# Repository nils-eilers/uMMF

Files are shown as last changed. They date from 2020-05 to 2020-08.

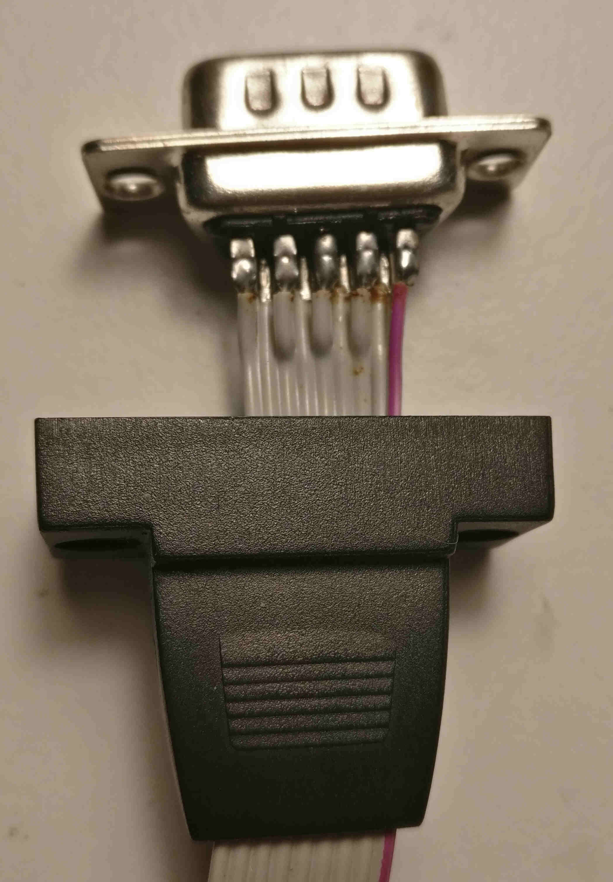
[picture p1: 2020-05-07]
doc/subd9-dtk-intel.jpg

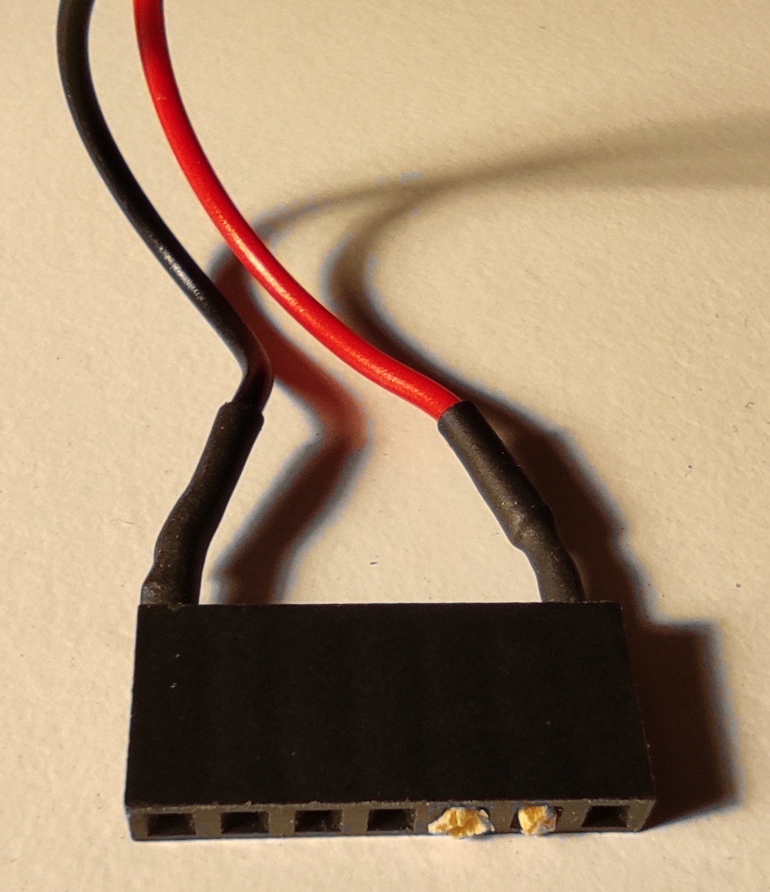
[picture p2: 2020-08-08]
doc/cable-j5-8032-j11.jpg

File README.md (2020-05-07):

µMMF
====

The SuperPET is basically a Commodore CBM 8032 with two, later only one
extra boards in it which contain a 6809 CPU, 64 KB RAM and some ROMs. This
project aims to provide a replacement for these extra board(s) with
slightly more modern parts, enabling every CBM 8032 owner to upgrade his
machine to a SuperPET.

__This board requires a NMOS 6502. Do NOT use a CMOS 6502!__

The board will accept NMOS Motorola 6809E as well as CMOS Hitachi HD63C09E,
just ensure you get the E-type, not those without appended ‘E’ because
their pinout is different. The version without E has the clock generator
integrated, the E-version requires an external clock generator.

LED D1 is a low current (2 mA) type. It is used solely for debug purposes,
the original SuperPET does not contain such a LED, so you may omit it.

IC3 74HCT11 has to be a HCT type. Do not use HC, LS or anything else
because HCT was chosen to match the voltage level requirements.

Please note that some modifications on the original CBM 8032 motherboard
must been made, as on the original SuperPET boards:

- 16 MHz clock signal provided at pin 35 of the 6502 CPU socket (patched in
  with a wire)
- 2532 character EPROM replacement

Refer to the pictures provided in the doc subdirectory for information
about how to provide the 16 MHz clock signal at pin 35. These differ
slightly from board version to board version.

An Atmel AT29C010 Flash ROM is required, programmed with roms/superpet.bin
and write protected.

The CPLD code was written in Verilog. These were my first steps with
Verilog, so please bear with me. Use Altera Quartus II 13.0.1 SP1 to
compile the Verilog and program the CPLD, newer versions don't support
the MAX7000 CPLD series any longer. The binary to program the CPLD is
located at cpld/output_files/superpet.pof.

An interactive bill of materials is available at `bom/ibom.html`

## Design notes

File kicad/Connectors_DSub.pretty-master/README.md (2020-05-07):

### Connectors_DSub

Footprints for DB / Dsubmiature / MicroD footprints

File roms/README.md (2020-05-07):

µMMF ROMs
=========

Nothing spectacular here, the waterloo ROM files are just concatenated
and empty spaces filled with $FF with the help of the Arnold Assembler AS,
freely available from http://john.ccac.rwth-aachen.de:8000/as/index.html

The generated file `superpet.bin` is to be flashed into an Atmel AT29C010A.
Ensure to enable the write protection of the flash ROM afterwards or the
contents will corrupt sooner or later.

Burn the file `characters.901640-01.bin` into a 2532 EPROM and replace
the character generator with it, otherwise you won't be able to see
anything.

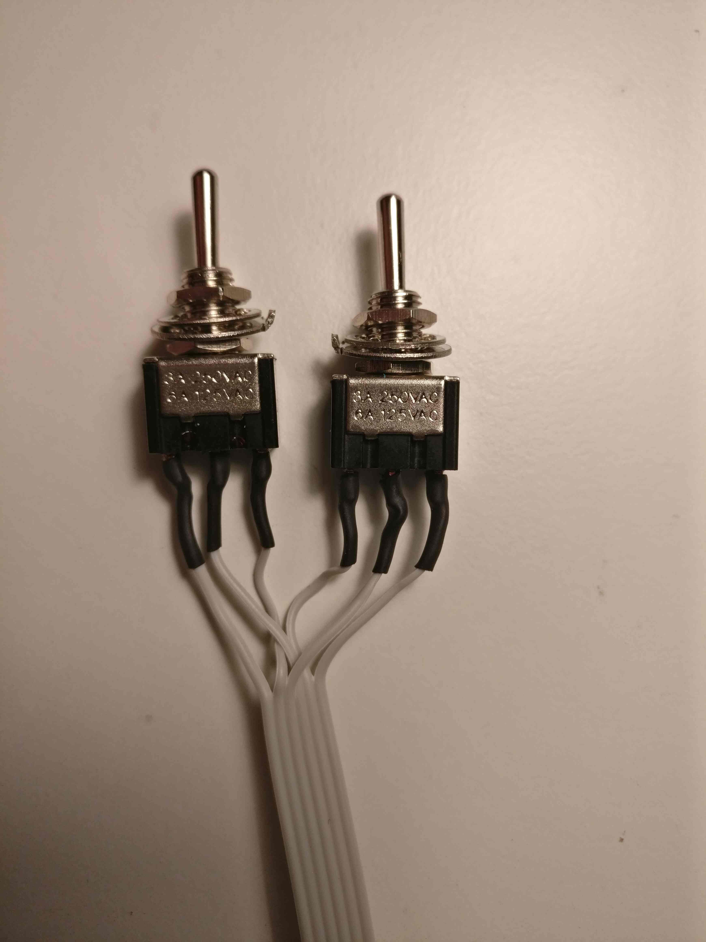
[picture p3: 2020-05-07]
doc/superpet-switches.jpg

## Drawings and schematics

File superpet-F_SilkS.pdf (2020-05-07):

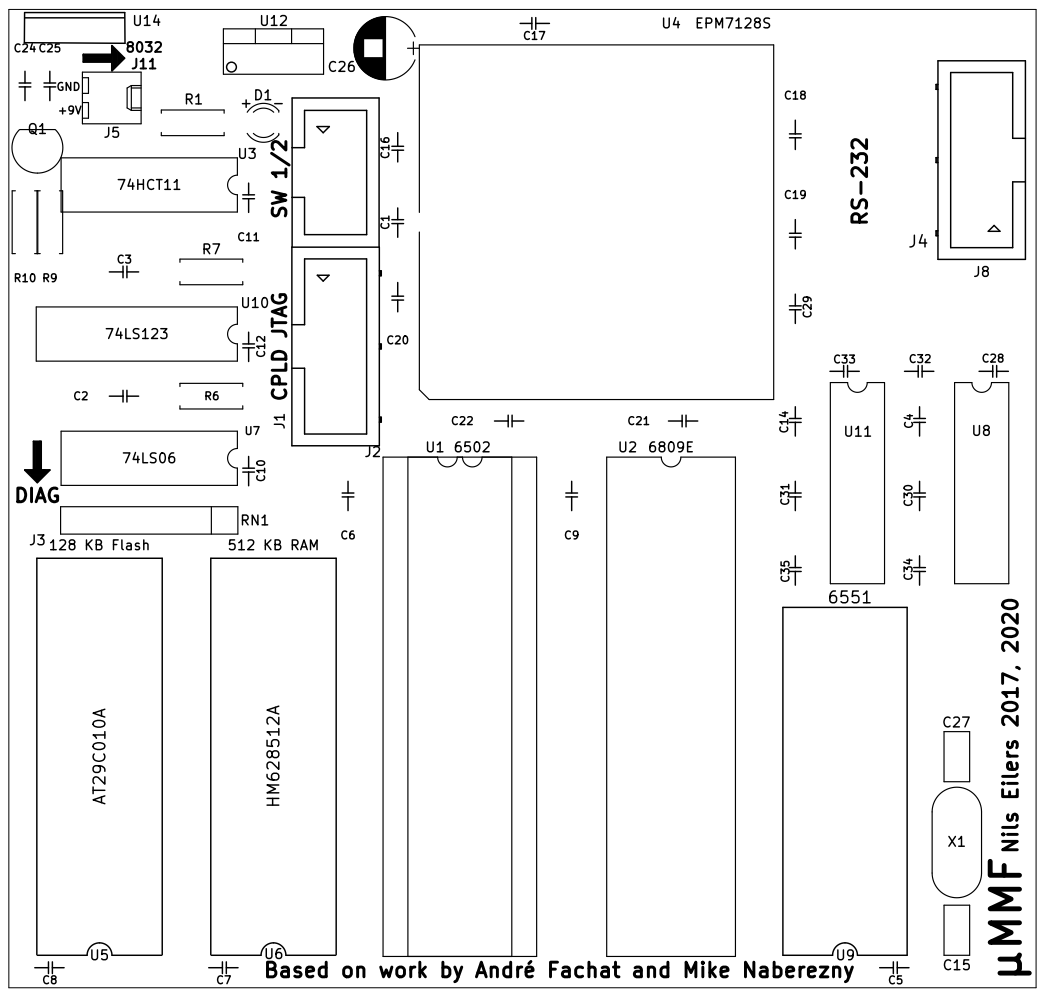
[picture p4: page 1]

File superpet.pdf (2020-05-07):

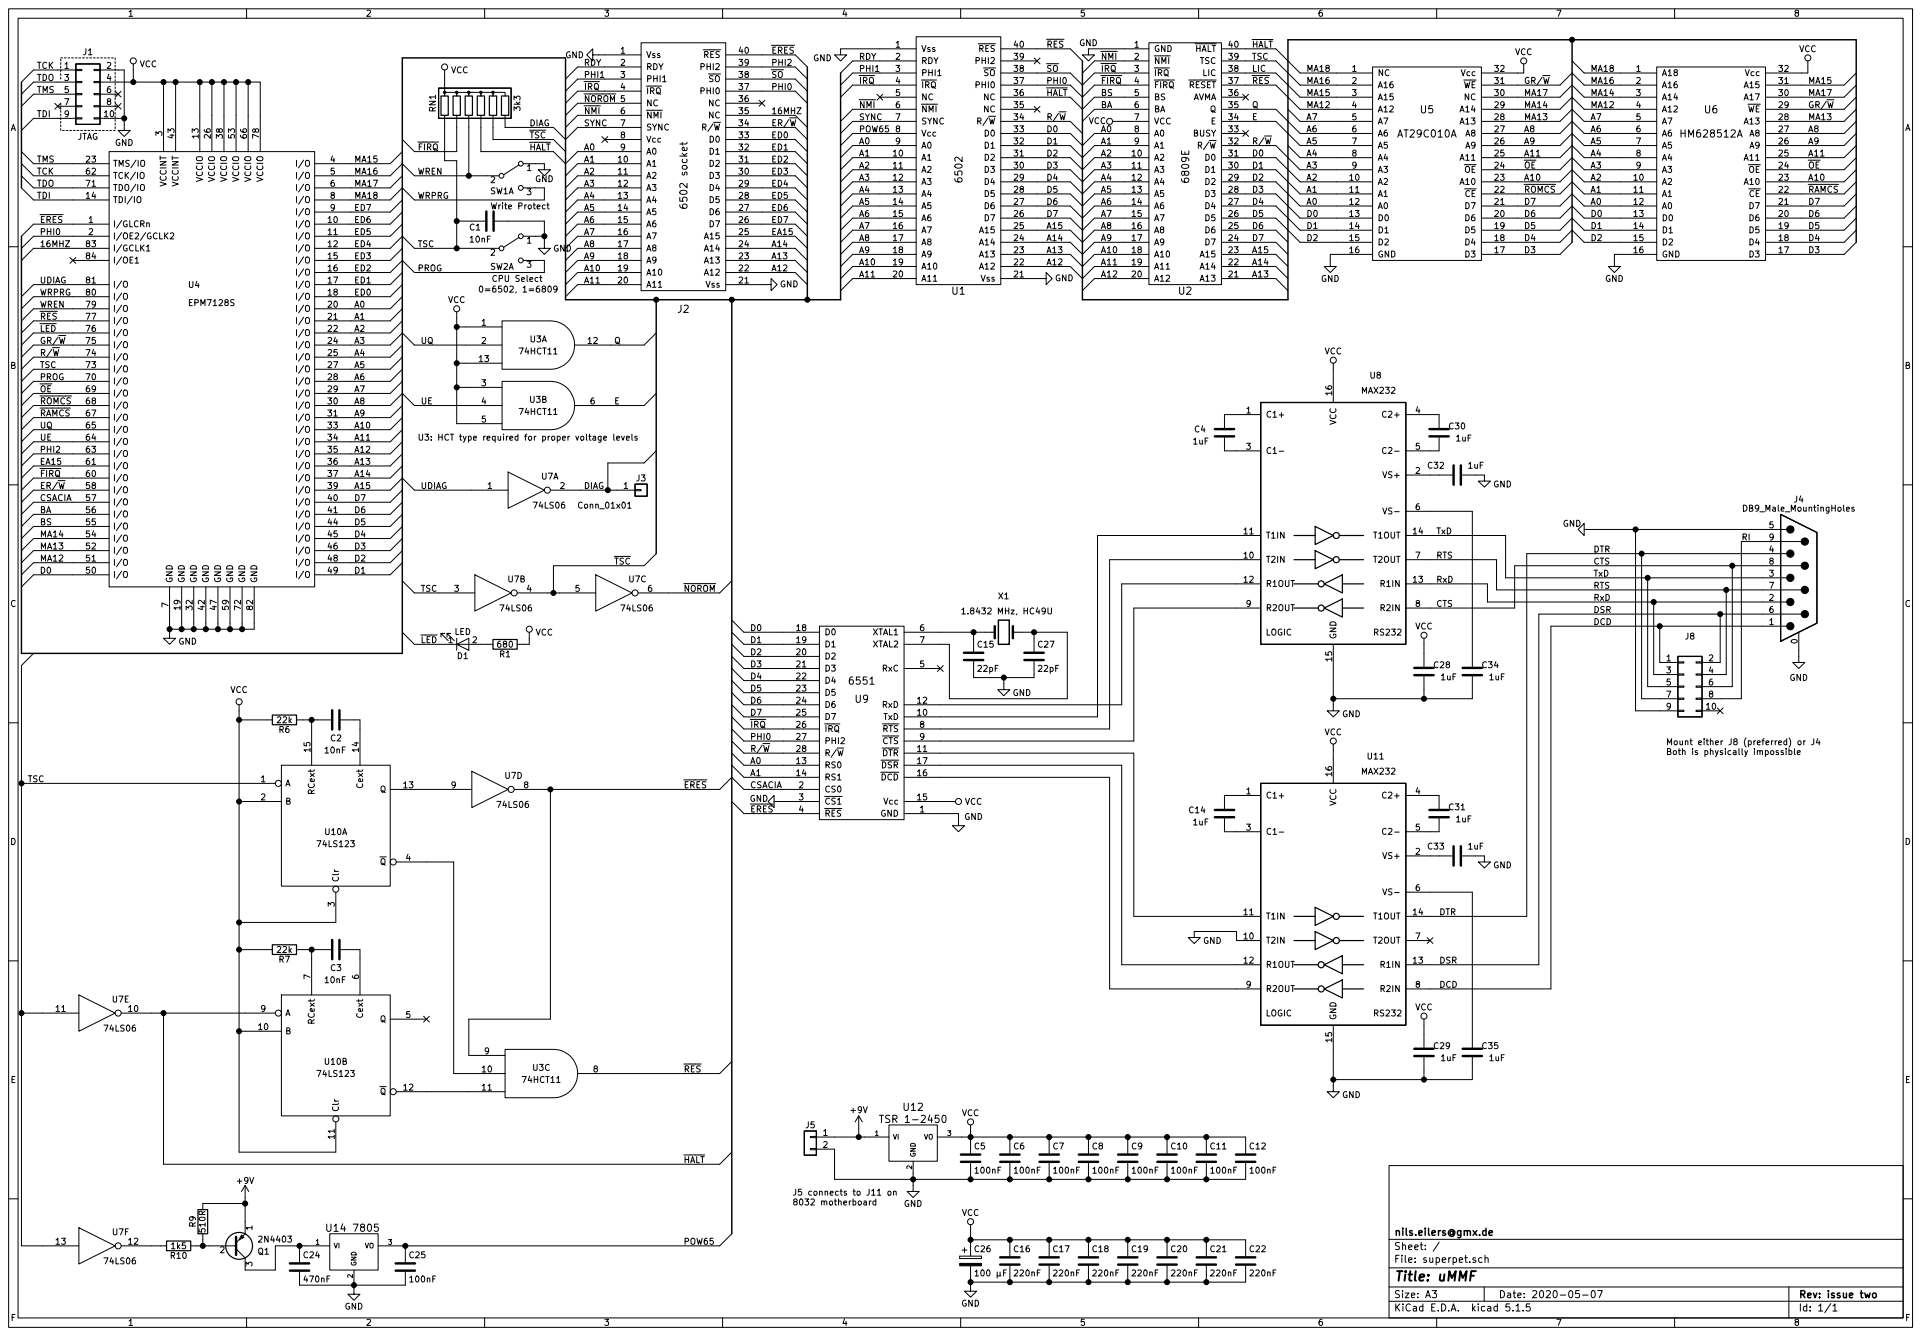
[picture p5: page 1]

A0 ROMCS R/W
WREN WRPRG
TDO

RTS RxD

TxD

Both is physically impossible

File: superpet.sch Sheet: / nils.eilers@gmx.de

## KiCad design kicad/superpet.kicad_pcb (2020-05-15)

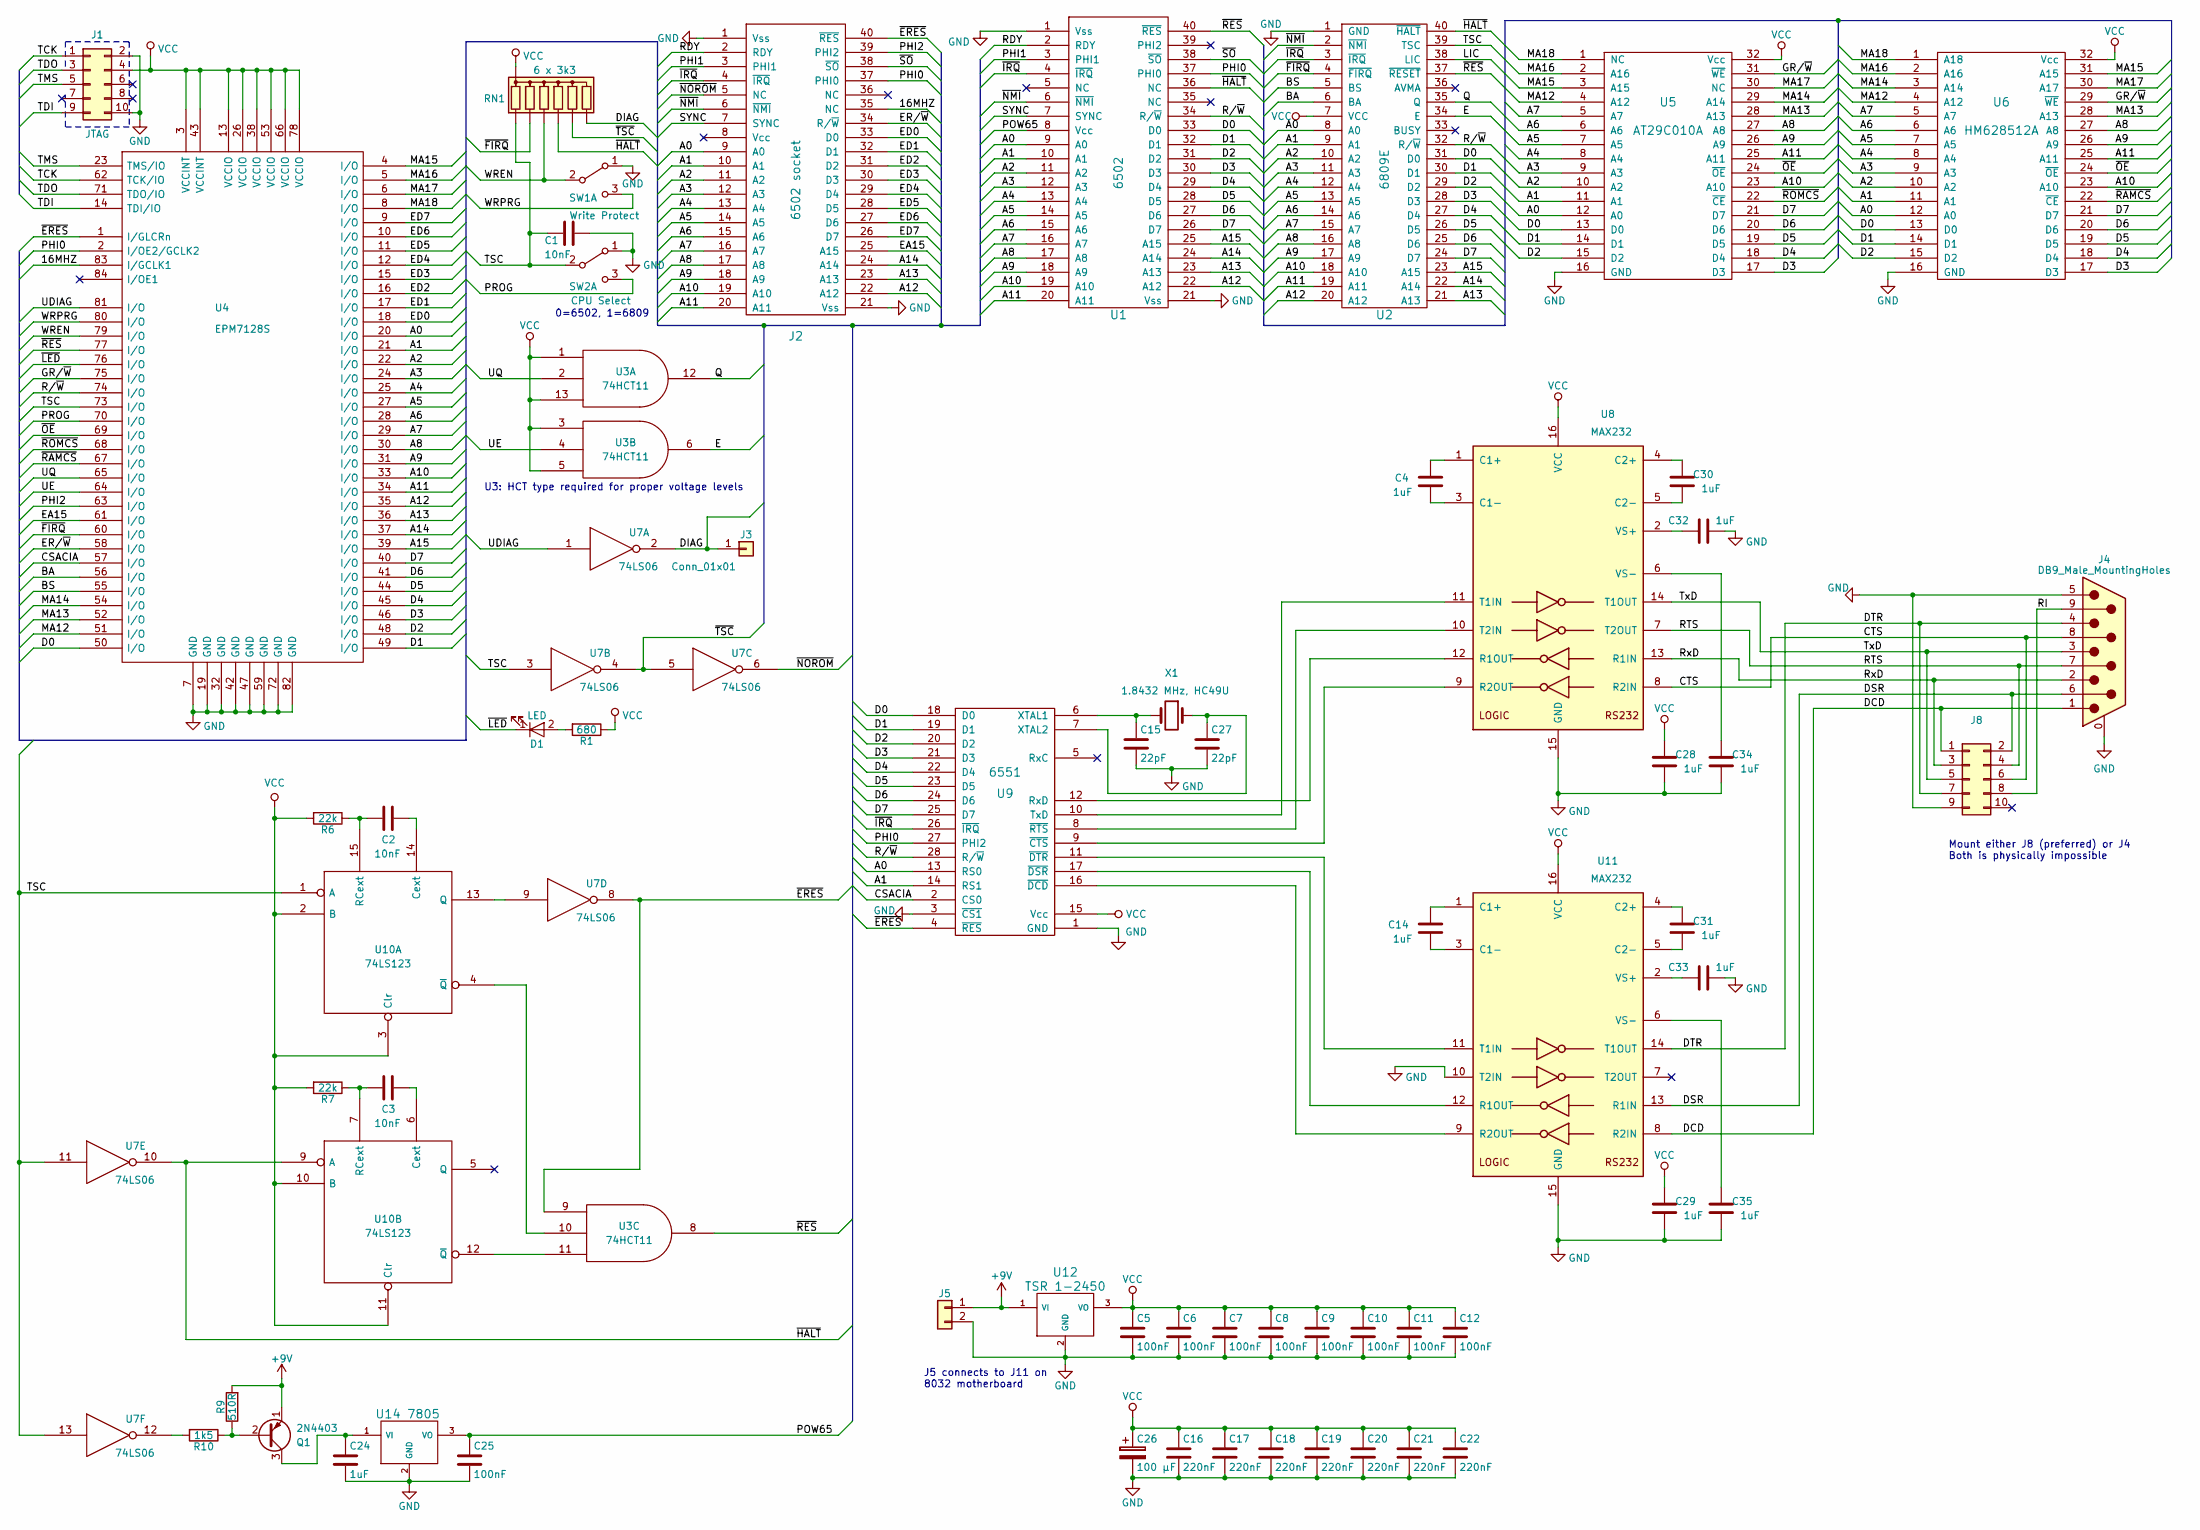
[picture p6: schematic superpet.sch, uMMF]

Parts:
C1, C2, C3: 10nF; C_Disc_D5.0mm_W2.5mm_P5.00mm
C4, C14, C24, C28, C29, C30, C31, C32, C33, C34, C35: 1uF; C_Disc_D5.0mm_W2.5mm_P5.00mm
C5, C6, C7, C8, C9, C10, C11, C12, C25: 100nF; C_Disc_D5.0mm_W2.5mm_P5.00mm
C15, C27: 22pF; C_Disc_D5.0mm_W2.5mm_P2.50mm
C16, C17, C18, C19, C20, C21, C22: 220nF; C_Disc_D5.0mm_W2.5mm_P5.00mm
C26: 100 µF; CP_Radial_D6.3mm_P2.50mm
D1: LED; LED_D3.0mm
J1: JTAG; Multicomp_MC9A12-1034_2x05x2.54mm_Straight
J2: 6502 socket; DIP-40_W15.24mm
J3: Conn_01x01; SolderWirePad_single_1mmDrill
J4: DB9_Male_MountingHoles; DB9MC
J5: Conn_01x02; Molex_KK-6410-02_02x2.54mm_Straight
J8: Conn_02x05_Odd_Even; Multicomp_MC9A12-1034_2x05x2.54mm_Straight
Q1: 2N4403; TO-92
R1: 680; R_Axial_DIN0207_L6.3mm_D2.5mm_P7.62mm_Horizontal
R6, R7: 22k; R_Axial_DIN0207_L6.3mm_D2.5mm_P7.62mm_Horizontal
R9: 510R; R_Axial_DIN0207_L6.3mm_D2.5mm_P7.62mm_Horizontal
R10: 1k5; R_Axial_DIN0207_L6.3mm_D2.5mm_P7.62mm_Horizontal
RN1: 6 x 3k3; R_Array_SIP7
SW1: Write Protect; WSL_6W_HALF
SW2: CPU Select; WSL_6W_HALF
U1: 6502; DIP-40_W15.24mm
U2: 6809E; DIP-40_W15.24mm
U3: 74HCT11; DIP-14_W7.62mm
U4: EPM7128S; PLCC-84_THT-Socket
U5: AT29C010A; DIP-32-15.24
U6: HM628512A; DIP-32-15.24
U7: 74LS06; DIP-14_W7.62mm
U8, U11: MAX232; DIP-16_W7.62mm
U9: 6551; DIP-28
U10: 74LS123; DIP-16_W7.62mm
U12: TSR 1-2450; TO-220-3_Vertical
U14: 7805; TO-220-3_Vertical
X1: 1.8432 MHz, HC49U; Crystal_HC49-U_Vertical

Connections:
+9V: J5.1, Q1.1 (E), R9.2, U12.1 (VI)
/16MHZ: J2.35 (NC), U4.83 (I/GCLK1)
/A0: J2.9 (A0), U1.9 (A0), U2.8 (A0), U4.20 (I/O), U5.12 (A0), U6.12 (A0), U9.13 (RS0)
/A1: J2.10 (A1), U1.10 (A1), U2.9 (A1), U4.21 (I/O), U5.11 (A1), U6.11 (A1), U9.14 (RS1)
/A2: J2.11 (A2), U1.11 (A2), U2.10 (A2), U4.22 (I/O), U5.10 (A2), U6.10 (A2)
/A3: J2.12 (A3), U1.12 (A3), U2.11 (A3), U4.24 (I/O), U5.9 (A3), U6.9 (A3)
/A4: J2.13 (A4), U1.13 (A4), U2.12 (A4), U4.25 (I/O), U5.8 (A4), U6.8 (A4)
/A5: J2.14 (A5), U1.14 (A5), U2.13 (A5), U4.27 (I/O), U5.7 (A5), U6.7 (A5)
/A6: J2.15 (A6), U1.15 (A6), U2.14 (A6), U4.28 (I/O), U5.6 (A6), U6.6 (A6)
/A7: J2.16 (A7), U1.16 (A7), U2.15 (A7), U4.29 (I/O), U5.5 (A7), U6.5 (A7)
/A8: J2.17 (A8), U1.17 (A8), U2.16 (A8), U4.30 (I/O), U5.27 (A8), U6.27 (A8)
/A9: J2.18 (A9), U1.18 (A9), U2.17 (A9), U4.31 (I/O), U5.26 (A9), U6.26 (A9)
/A10: J2.19 (A10), U1.19 (A10), U2.18 (A10), U4.33 (I/O), U5.23 (A10), U6.23 (A10)
/A11: J2.20 (A11), U1.20 (A11), U2.19 (A11), U4.34 (I/O), U5.25 (A11), U6.25 (A11)
/A12: J2.22 (A12), U1.22 (A12), U2.20 (A12), U4.35 (I/O)
/A13: J2.23 (A13), U1.23 (A13), U2.21 (A13), U4.36 (I/O)
/A14: J2.24 (A14), U1.24 (A14), U2.22 (A14), U4.37 (I/O)
/A15: U1.25 (A15), U2.23 (A15), U4.39 (I/O)
/BA: U2.6 (BA), U4.56 (I/O)
/BS: U2.5 (BS), U4.55 (I/O)
/CSACIA: U4.57 (I/O), U9.2 (CS0)
/CTS: J4.8, J8.6, U8.8 (R2IN)
/D0: U1.33 (D0), U2.31 (D0), U4.50 (I/O), U5.13 (D0), U6.13 (D0), U9.18 (D0)
/D1: U1.32 (D1), U2.30 (D1), U4.49 (I/O), U5.14 (D1), U6.14 (D1), U9.19 (D1)
/D2: U1.31 (D2), U2.29 (D2), U4.48 (I/O), U5.15 (D2), U6.15 (D2), U9.20 (D2)
/D3: U1.30 (D3), U2.28 (D3), U4.46 (I/O), U5.17 (D3), U6.17 (D3), U9.21 (D3)
/D4: U1.29 (D4), U2.27 (D4), U4.45 (I/O), U5.18 (D4), U6.18 (D4), U9.22 (D4)
/D5: U1.28 (D5), U2.26 (D5), U4.44 (I/O), U5.19 (D5), U6.19 (D5), U9.23 (D5)
/D6: U1.27 (D6), U2.25 (D6), U4.41 (I/O), U5.20 (D6), U6.20 (D6), U9.24 (D6)
/D7: U1.26 (D7), U2.24 (D7), U4.40 (I/O), U5.21 (D7), U6.21 (D7), U9.25 (D7)
/DCD: J4.1, J8.1, U11.8 (R2IN)
/DIAG: J3.1, RN1.7 (R6), U7.2
/DSR: J4.6, J8.2, U11.13 (R1IN)
/DTR: J4.4, J8.7, U11.14 (T1OUT)
/E: U2.34 (E), U3.6
/EA15: J2.25 (A15), U4.61 (I/O)
/ED0: J2.33 (D0), U4.18 (I/O)
/ED1: J2.32 (D1), U4.17 (I/O)
/ED2: J2.31 (D2), U4.16 (I/O)
/ED3: J2.30 (D3), U4.15 (I/O)
/ED4: J2.29 (D4), U4.12 (I/O)
/ED5: J2.28 (D5), U4.11 (I/O)
/ED6: J2.27 (D6), U4.10 (I/O)
/ED7: J2.26 (D7), U4.9 (I/O)
/ER/~W: J2.34 (R/~W), U4.58 (I/O)
/GR/~W: U4.75 (I/O), U5.31 (~WE), U6.29 (~WE)
/LIC: U2.38 (LIC)
/MA12: U4.51 (I/O), U5.4 (A12), U6.4 (A12)
/MA13: U4.52 (I/O), U5.28 (A13), U6.28 (A13)
/MA14: U4.54 (I/O), U5.29 (A14), U6.3 (A14)
/MA15: U4.4 (I/O), U5.3 (A15), U6.31 (A15)
/MA16: U4.5 (I/O), U5.2 (A16), U6.2 (A16)
/MA17: U4.6 (I/O), U5.30 (NC), U6.30 (A17)
/MA18: U4.8 (I/O), U5.1 (NC), U6.1 (A18)
/PHI0: J2.37 (PHI0), U1.37 (PHI0), U4.2 (I/OE2/GCLK2), U9.27 (PHI2)
/PHI1: J2.3 (PHI1), U1.3 (PHI1)
/PHI2: J2.39 (PHI2), U4.63 (I/O)
/POW65: C25.1, U1.8 (Vcc), U14.3 (VO)
/PROG: SW2.3 (C), U4.70 (I/O)
/Q: U2.35 (Q), U3.12
/R/~W: U1.34 (R/~W), U2.32 (R/~W), U4.74 (I/O), U9.28 (R/~W)
/RDY: J2.2 (RDY), U1.2 (RDY)
/RI: J4.9, J8.8
/RTS: J4.7, J8.4, U8.7 (T2OUT)
/RxD: J4.2, J8.3, U8.13 (R1IN)
/SYNC: J2.7 (SYNC), U1.7 (SYNC)
/TCK: J1.1, U4.62 (TCK/IO)
/TDI: J1.9, U4.14 (TDI/IO)
/TDO: J1.3, U4.71 (TDO/IO)
/TMS: J1.5, U4.23 (TMS/IO)
/TSC: C1.2, RN1.2 (R1), SW2.2 (B), U2.39 (TSC), U4.73 (I/O), U7.3, U7.11, U7.13, U10.1 (A)
/TxD: J4.3, J8.5, U8.14 (T1OUT)
/UDIAG: U4.81 (I/O), U7.1
/UE: U3.4, U4.64 (I/O)
/UQ: U3.2, U4.65 (I/O)
/WREN: RN1.4 (R3), SW1.2 (B), U4.79 (I/O)
/WRPRG: SW1.3 (C), U4.80 (I/O)
/~ERES: J2.40 (~RES), U3.9, U4.1 (I/GLCRn), U7.8, U9.4 (~RES)
/~FIRQ: RN1.3 (R2), U2.4 (~FIRQ), U4.60 (I/O)
/~HALT: RN1.5 (R4), U1.36 (NC), U2.40 (~HALT), U7.10, U10.9 (A)
/~IRQ: J2.4 (~IRQ), U1.4 (~IRQ), U2.3 (~IRQ), U9.26 (~IRQ)
/~LED: D1.1 (K), U4.76 (I/O)
/~NMI: J2.6 (~NMI), U1.6 (~NMI), U2.2 (~NMI)
/~NOROM: J2.5 (NC), U7.6
/~OE: U4.69 (I/O), U5.24 (~OE), U6.24 (~OE)
/~RAMCS: U4.67 (I/O), U6.22 (~CE)
/~RES: U1.40 (~RES), U2.37 (~RESET), U3.8, U4.77 (I/O)
/~ROMCS: U4.68 (I/O), U5.22 (~CE)
/~SO: J2.38 (~SO), U1.38 (~SO)
/~TSC: RN1.6 (R5), U7.4, U7.5
GND: C1.1, C5.2, C6.2, C7.2, C8.2, C9.2, C10.2, C11.2, C12.2, C15.2, C16.2, C17.2, C18.2, C19.2, C20.2, C21.2, C22.2, C24.2, C25.2, C26.2, C27.2, C28.1, C29.1, C32.2, C33.2, C34.1, C35.1, J1.2, J1.10, J2.1 (Vss), J2.21 (Vss), J4.0 (PAD), J4.5, J5.2, J8.9, SW1.1 (A), SW2.1 (A), U1.1 (Vss), U1.21 (Vss), U2.1 (GND), U3.7 (GND), U4.7 (GND), U4.19 (GND), U4.32 (GND), U4.42 (GND), U4.47 (GND), U4.59 (GND), U4.72 (GND), U4.82 (GND), U5.16 (GND), U6.16 (GND), U7.7 (GND), U8.15 (GND), U9.1 (GND), U9.3 (~CS1), U10.8 (GND), U11.10 (T2IN), U11.15 (GND), U12.2 (GND), U14.2 (GND)
unnamed: C2.1, U10.14 (Cext)
unnamed: C2.2, R6.1, U10.15 (RCext)
unnamed: C3.1, U10.6 (Cext)
unnamed: C3.2, R7.1, U10.7 (RCext)
unnamed: C4.1, U8.3 (C1-)
unnamed: C4.2, U8.1 (C1+)
unnamed: C14.1, U11.3 (C1-)
unnamed: C14.2, U11.1 (C1+)
unnamed: C15.1, U9.6 (XTAL1), X1.2
unnamed: C24.1, Q1.3 (C), U14.1 (VI)
unnamed: C27.1, U9.7 (XTAL2), X1.1
unnamed: C30.1, U8.5 (C2-)
unnamed: C30.2, U8.4 (C2+)
unnamed: C31.1, U11.5 (C2-)
unnamed: C31.2, U11.4 (C2+)
unnamed: C32.1, U8.2 (VS+)
unnamed: C33.1, U11.2 (VS+)
unnamed: C34.2, U8.6 (VS-)
unnamed: C35.2, U11.6 (VS-)
unnamed: D1.2 (A), R1.2
unnamed: Q1.2 (B), R9.1, R10.1
unnamed: R10.2, U7.12
unnamed: U8.9 (R2OUT), U9.9 (~CTS)
unnamed: U8.10 (T2IN), U9.8 (~RTS)
unnamed: U8.11 (T1IN), U9.10 (TxD)
unnamed: U8.12 (R1OUT), U9.12 (RxD)
unnamed: U3.10, U10.4 (~Q)
unnamed: U3.11, U10.12 (~Q)
unnamed: U7.9, U10.13 (Q)
unnamed: U9.16 (~DCD), U11.9 (R2OUT)
unnamed: U9.11 (~DTR), U11.11 (T1IN)
unnamed: U9.17 (~DSR), U11.12 (R1OUT)
VCC: C5.1, C6.1, C7.1, C8.1, C9.1, C10.1, C11.1, C12.1, C16.1, C17.1, C18.1, C19.1, C20.1, C21.1, C22.1, C26.1, C28.2, C29.2, J1.4, R1.1, R6.2, R7.2, RN1.1 (common), U2.7 (VCC), U3.1, U3.3, U3.5, U3.13, U3.14 (VCC), U4.3 (VCCINT), U4.13 (VCCIO), U4.26 (VCCIO), U4.38 (VCCIO), U4.43 (VCCINT), U4.53 (VCCIO), U4.66 (VCCIO), U4.78 (VCCIO), U5.32 (Vcc), U6.32 (Vcc), U7.14 (VCC), U8.16 (VCC), U9.15 (Vcc), U10.2 (B), U10.3 (Clr), U10.10 (B), U10.11 (Clr), U10.16 (VCC), U11.16 (VCC), U12.3 (VO)

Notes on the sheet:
0=6502, 1=6809
U3: HCT type required for proper voltage levels
J5 connects to J11 on 8032 motherboard
Mount either J8 (preferred) or J4 Both is physically impossible

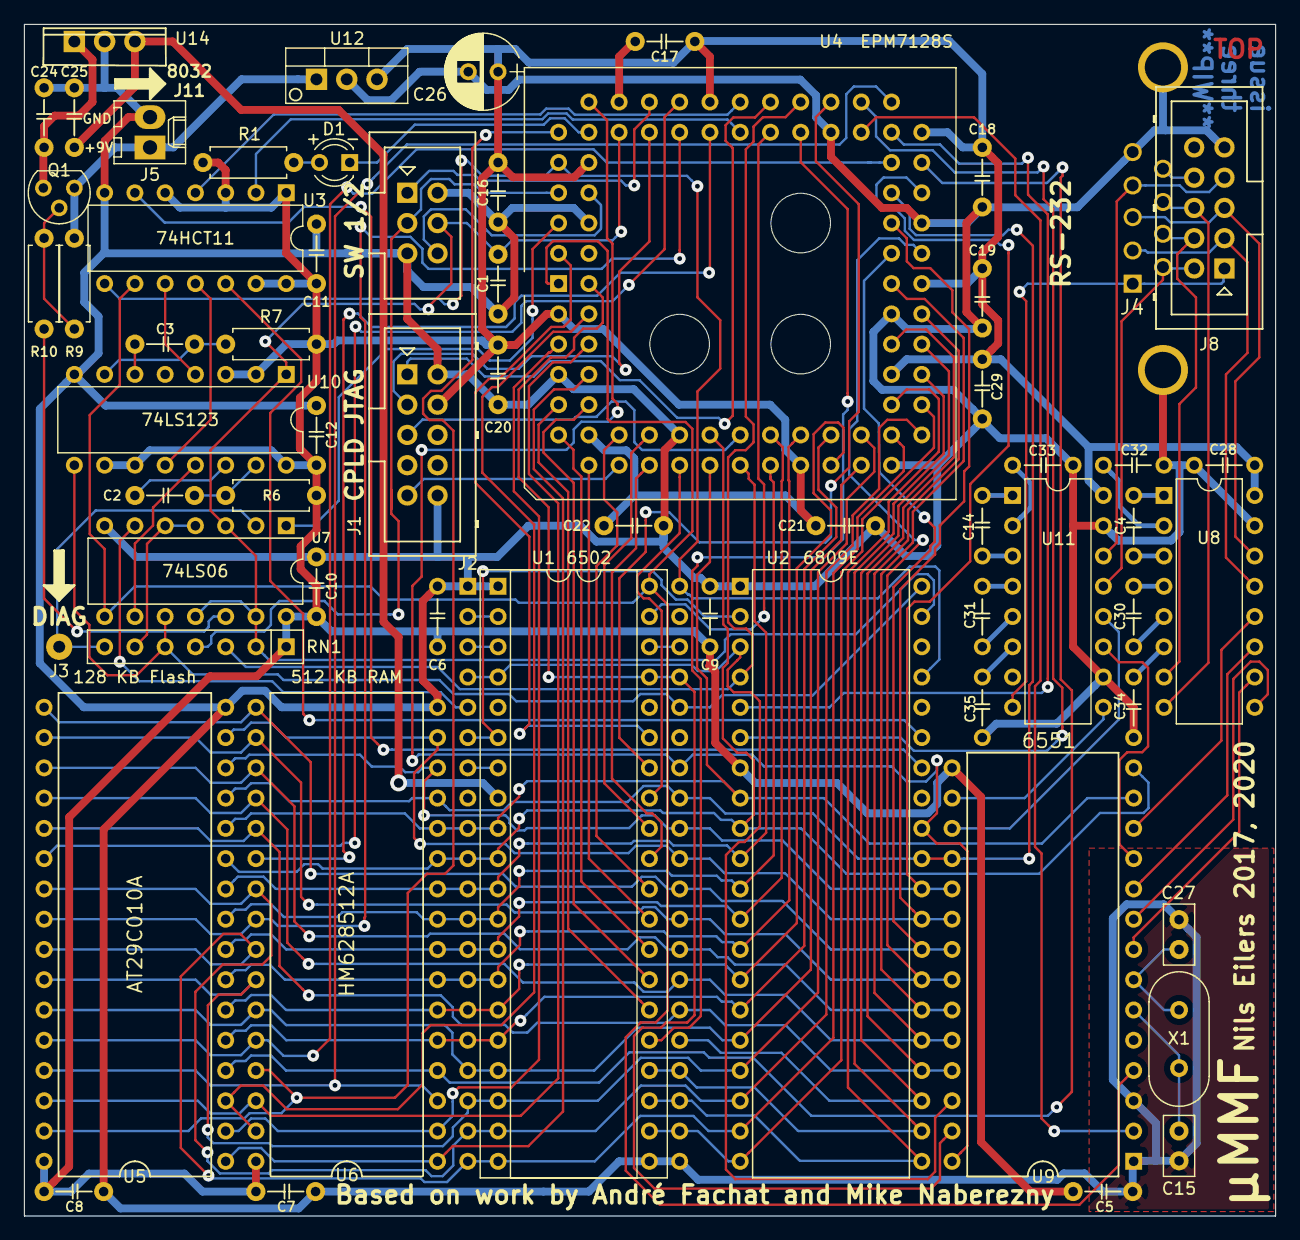
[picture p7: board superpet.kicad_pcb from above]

Board: 2 copper layers, 105.0 x 100.0 mm, 66 parts (0 on the bottom side), 123 nets.

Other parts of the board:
H1, H2, H3: Pin_Header_Straight_1x01_Pitch2.54mm

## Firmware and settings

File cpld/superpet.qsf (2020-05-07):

# -------------------------------------------------------------------------- #
#
# Copyright (C) 1991-2013 Altera Corporation
# Your use of Altera Corporation's design tools, logic functions 
# and other software and tools, and its AMPP partner logic 
# functions, and any output files from any of the foregoing 
# (including device programming or simulation files), and any 
# associated documentation or information are expressly subject 
# to the terms and conditions of the Altera Program License 
# Subscription Agreement, Altera MegaCore Function License 
# Agreement, or other applicable license agreement, including, 
# without limitation, that your use is for the sole purpose of 
# programming logic devices manufactured by Altera and sold by 
# Altera or its authorized distributors.  Please refer to the 
# applicable agreement for further details.
#
# -------------------------------------------------------------------------- #
#
# Quartus II 64-Bit
# Version 13.0.1 Build 232 06/12/2013 Service Pack 1 SJ Web Edition
# Date created = 00:10:47  December 24, 2017
#
# -------------------------------------------------------------------------- #
#
# Notes:
#
# 1) The default values for assignments are stored in the file:
#		superpet_assignment_defaults.qdf
#    If this file doesn't exist, see file:
#		assignment_defaults.qdf
#
# 2) Altera recommends that you do not modify this file. This
#    file is updated automatically by the Quartus II software
#    and any changes you make may be lost or overwritten.
#
# -------------------------------------------------------------------------- #


set_global_assignment -name FAMILY MAX7000S
set_global_assignment -name DEVICE "EPM7128SLC84-15"
set_global_assignment -name TOP_LEVEL_ENTITY superpet
set_global_assignment -name ORIGINAL_QUARTUS_VERSION "13.0 SP1"
set_global_assignment -name PROJECT_CREATION_TIME_DATE "00:10:47  DECEMBER 24, 2017"
set_global_assignment -name LAST_QUARTUS_VERSION "13.0 SP1"
set_global_assignment -name PROJECT_OUTPUT_DIRECTORY output_files
set_global_assignment -name EDA_SIMULATION_TOOL "ModelSim-Altera (VHDL)"
set_global_assignment -name EDA_OUTPUT_DATA_FORMAT VHDL -section_id eda_simulation
set_instance_assignment -name PARTITION_HIERARCHY root_partition -to | -section_id Top
set_global_assignment -name PARTITION_NETLIST_TYPE SOURCE -section_id Top
set_global_assignment -name PARTITION_FITTER_PRESERVATION_LEVEL PLACEMENT_AND_ROUTING -section_id Top
set_global_assignment -name PARTITION_COLOR 16764057 -section_id Top
set_global_assignment -name DEVICE_FILTER_PACKAGE PLCC
set_global_assignment -name DEVICE_FILTER_PIN_COUNT 84
set_global_assignment -name USE_CONFIGURATION_DEVICE OFF
set_global_assignment -name RESERVE_ALL_UNUSED_PINS_NO_OUTPUT_GND "AS INPUT TRI-STATED"
set_global_assignment -name TIMEQUEST_MULTICORNER_ANALYSIS OFF
set_global_assignment -name OPTIMIZE_HOLD_TIMING "ALL PATHS"
set_global_assignment -name OPTIMIZE_MULTI_CORNER_TIMING OFF
set_global_assignment -name FITTER_EFFORT "STANDARD FIT"
set_global_assignment -name SLOW_SLEW_RATE ON
set_global_assignment -name AUTO_TURBO_BIT OFF
set_global_assignment -name TIMEQUEST_DO_CCPP_REMOVAL OFF
set_global_assignment -name MAX7000_DEVICE_IO_STANDARD TTL
set_global_assignment -name VERILOG_FILE superpet.v
set_global_assignment -name TIMEQUEST_REPORT_SCRIPT_INCLUDE_DEFAULT_ANALYSIS OFF
set_location_assignment PIN_51 -to MA12
set_location_assignment PIN_52 -to MA13
set_location_assignment PIN_54 -to MA14
set_location_assignment PIN_55 -to BS
set_location_assignment PIN_56 -to BA
set_location_assignment PIN_57 -to CSACIA
set_location_assignment PIN_58 -to ERW
set_location_assignment PIN_60 -to nFIRQ
set_location_assignment PIN_61 -to EA15
set_location_assignment PIN_63 -to PHI2
set_location_assignment PIN_64 -to uE
set_location_assignment PIN_65 -to uQ
set_location_assignment PIN_67 -to nRAMCS
set_location_assignment PIN_68 -to nROMCS
set_location_assignment PIN_69 -to nOE
set_location_assignment PIN_70 -to PROG
set_location_assignment PIN_73 -to TSC
set_location_assignment PIN_74 -to RW
set_location_assignment PIN_75 -to GRW
set_location_assignment PIN_77 -to nRES
set_location_assignment PIN_79 -to WREN
set_location_assignment PIN_80 -to WRPRG
set_location_assignment PIN_81 -to uDIAG
set_location_assignment PIN_4 -to MA15
set_location_assignment PIN_5 -to MA16
set_location_assignment PIN_6 -to MA17
set_location_assignment PIN_8 -to MA18
set_location_assignment PIN_1 -to nERES
set_location_assignment PIN_83 -to MHZ16
set_location_assignment PIN_20 -to A[0]
set_location_assignment PIN_9 -to ED[7]
set_location_assignment PIN_10 -to ED[6]
set_location_assignment PIN_11 -to ED[5]
set_location_assignment PIN_12 -to ED[4]
set_location_assignment PIN_15 -to ED[3]
set_location_assignment PIN_16 -to ED[2]
set_location_assignment PIN_17 -to ED[1]
set_location_assignment PIN_18 -to ED[0]
set_location_assignment PIN_21 -to A[1]
set_location_assignment PIN_22 -to A[2]
set_location_assignment PIN_24 -to A[3]
set_location_assignment PIN_25 -to A[4]
set_location_assignment PIN_27 -to A[5]
set_location_assignment PIN_28 -to A[6]
set_location_assignment PIN_29 -to A[7]
set_location_assignment PIN_30 -to A[8]
set_location_assignment PIN_31 -to A[9]
set_location_assignment PIN_33 -to A[10]
set_location_assignment PIN_34 -to A[11]
set_location_assignment PIN_35 -to A[12]
set_location_assignment PIN_36 -to A[13]
set_location_assignment PIN_37 -to A[14]
set_location_assignment PIN_39 -to A[15]
set_location_assignment PIN_40 -to D[7]
set_location_assignment PIN_41 -to D[6]
set_location_assignment PIN_44 -to D[5]
set_location_assignment PIN_45 -to D[4]
set_location_assignment PIN_46 -to D[3]
set_location_assignment PIN_48 -to D[2]
set_location_assignment PIN_49 -to D[1]
set_location_assignment PIN_50 -to D[0]
set_location_assignment PIN_2 -to PHI0
set_location_assignment PIN_76 -to LED
set_global_assignment -name SYNTH_TIMING_DRIVEN_SYNTHESIS OFF

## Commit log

2020-05-07 Clarify position of RI in RS-232 schematic
    [superpet.sch]
2020-05-07 Change resistor value for LED from 330 Ohm to 680 Ohm
    [superpet.sch]
2020-05-07 Increase capacitor value to 100 uF
    [superpet.sch]
2020-05-07 MAX232 version for CBM 8032 + CBM 8296
    [superpet-B_Cu.gbr, superpet-B_Mask.gbr, superpet-B_SilkS.gbr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]
2020-05-07 Update BOM
2020-05-15 Minor changes
    - version number changed to "issue three **WIP**"
    - Change capacitor near 7805 from 470nF to 1uF
    - larger solder pads for sub-d socket
    - clarify value of resistor network
    Caution: gerber files are not yet updated
    [superpet.kicad_pcb, superpet.sch]
2020-08-08 Add picture of power cable
